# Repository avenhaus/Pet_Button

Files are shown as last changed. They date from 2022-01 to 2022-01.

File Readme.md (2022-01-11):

# ESP32 Talking Pet Button Matrix

<br />
<div align="center">
  <a href="https://github.com/avenhaus/Pet_Button">
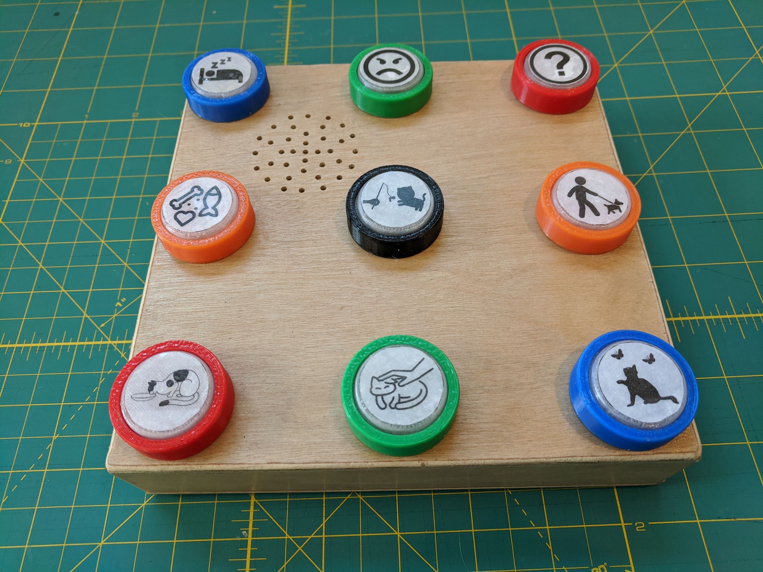
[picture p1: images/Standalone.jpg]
Main Image
    
  </a>
</div>

## Overview

Buttons are arranged on 3 x 3 panels = 9 buttons, requiring 6 wires per panel.
The ESP32 provides 9 inputs by 6 outputs for a support of 6 panels (**54 buttons**) per ESP32.
The audio is stored in ESP32 internal FLASH and played via an I2S amplifier like [MAX98357A](https://www.aliexpress.com/premium/MAX98357A.html?SearchText=MAX98357A)

Current custom 3D printed button is designed for cats or small dogs. It uses a cheap, low profile PCB push button inside and optional SMD LED.

## Advantages

Advantages over commercially available singe recording buttons.

* Better quality and louder audio playback through large 3 watt speaker.
* Higher quality, normalized, de-noised and trimmed recordings using PC microphone and software like [Audacity](https://www.audacityteam.org/)
* Buttons illuminate for additional feedback.
* Much cheaper for large number of buttons.
* Your own choice of button size, feel, look, etc.
* Single, larger battery for all buttons
* Optional AC or USB power

## Build Instructions

### Buttons

* Print icon labels on regular paper.
* Cover with clear packing tape for protection.
* Cut to size with scissors.
* Use CA glue (Super Glue) to attach icons to button caps.
* Hot glue works great to make cheap, leveled non-slip rubber feet. Offset panel on a silicone mat while hot glue cools. (Hot glue removes easily with rubbing alcohol from most surfaces.)

### Audio

* Record audio as 44.1 kHz mono.
* Convert to .m4a (96 kbps) or .mp3 format. .wav works but takes more space.
* Save audio files to to data folder.
* Flash data folder to ESP32 SPIFFS.
* Map audio file to button in *files.h*

## Libraries

* [ESP32-audioI2S](https://github.com/schreibfaul1/ESP32-audioI2S)

## Notes

If there is a noticeable delay between pressing the button and the audio playing, this is due to the default Arduino boot loader being slow to wake up from deep sleep. This can be fixed by flashing a correctly configured IDF boot loader: *bootloader.bin* .

```
.platformio\packages\tool-esptoolpy\esptool.py --chip esp32 --port "COM5" --baud 460800 --before default_reset --after hard_reset write_flash -z --flash_mode dio --flash_freq 40m --flash_size detect 0x1000 bootloader.bin
```

A few of the ESP32 pins can not be switched to output. This means not all buttons can be illuminated.

## Todo

* Code cleanup, license and documentation
* Easier audio management through ESP32 website
* OTA update
* PCB
* 3D printed case

## Images

### Stand alone panel for multiple locations or mobility.
Stand Alone Panel

### Multi panel setup with central audio box for maximum buttons
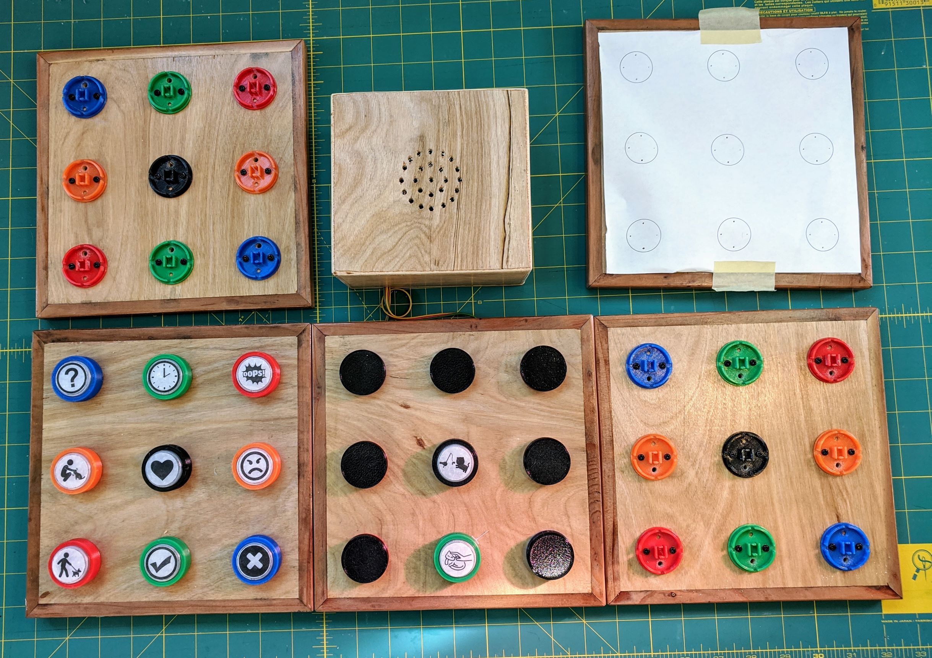
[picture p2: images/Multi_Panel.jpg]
Multi Panel


### Illuminated button
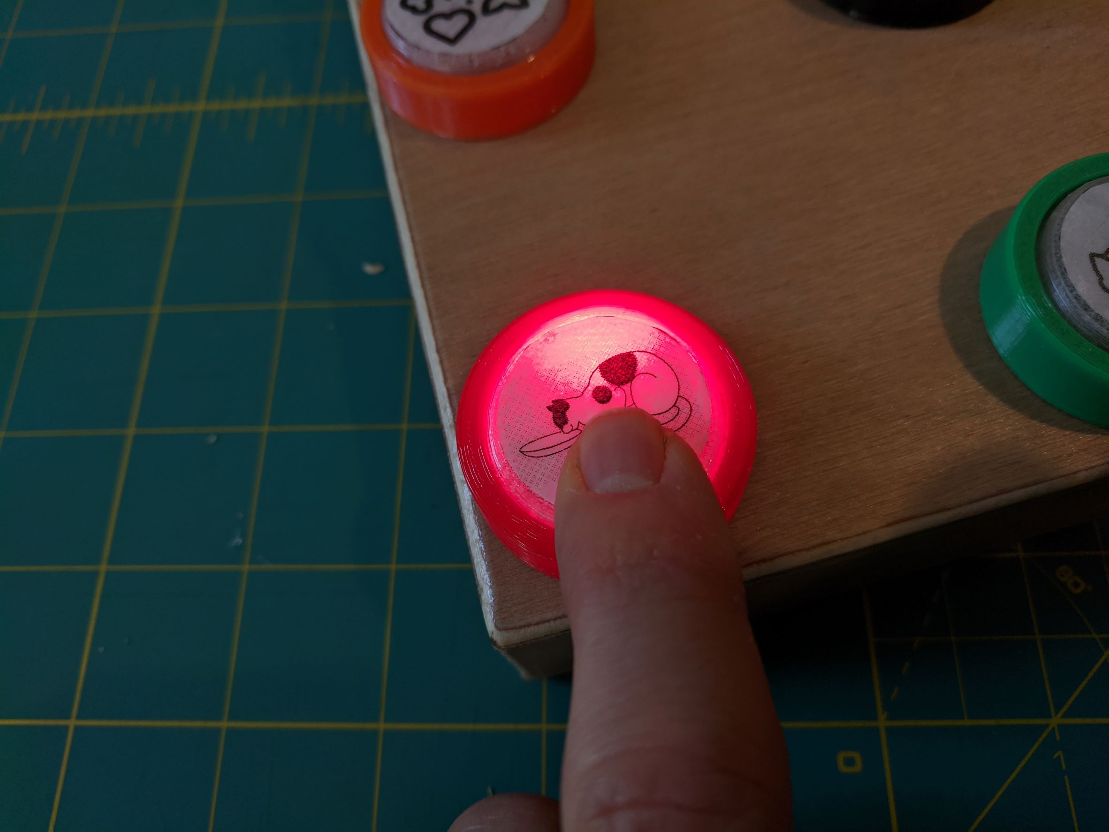
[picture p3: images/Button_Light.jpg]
Button Light


### Button uses cheap PCB push botton and SMD LED
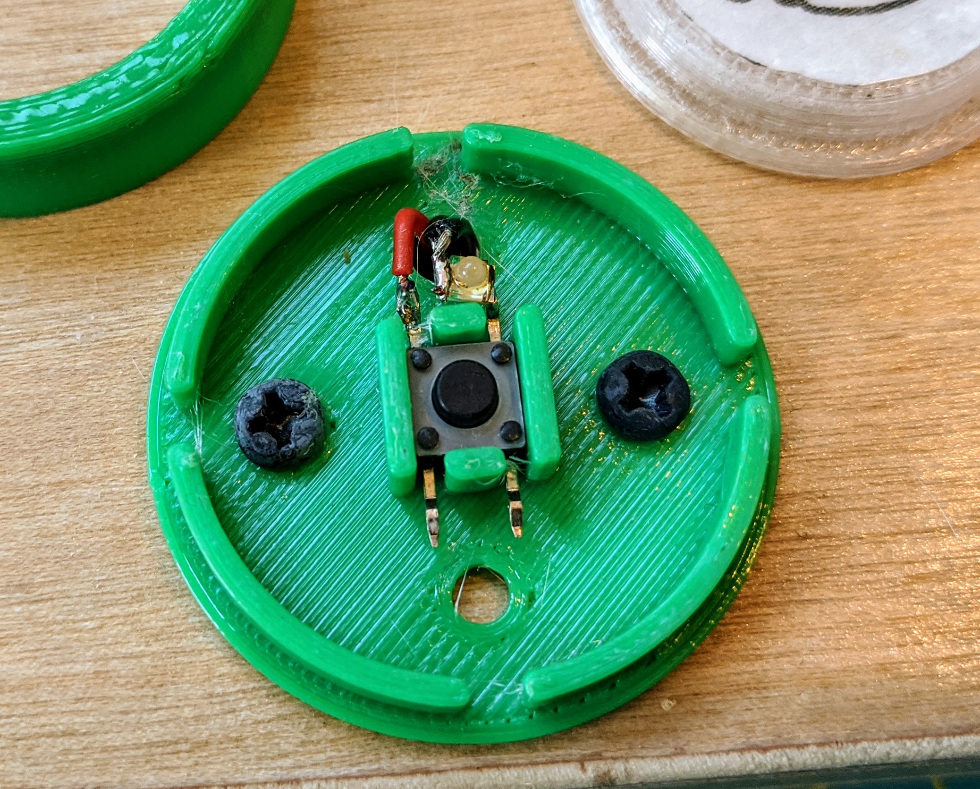
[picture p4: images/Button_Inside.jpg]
Button Inside


### Inside of Stand Alone Panel
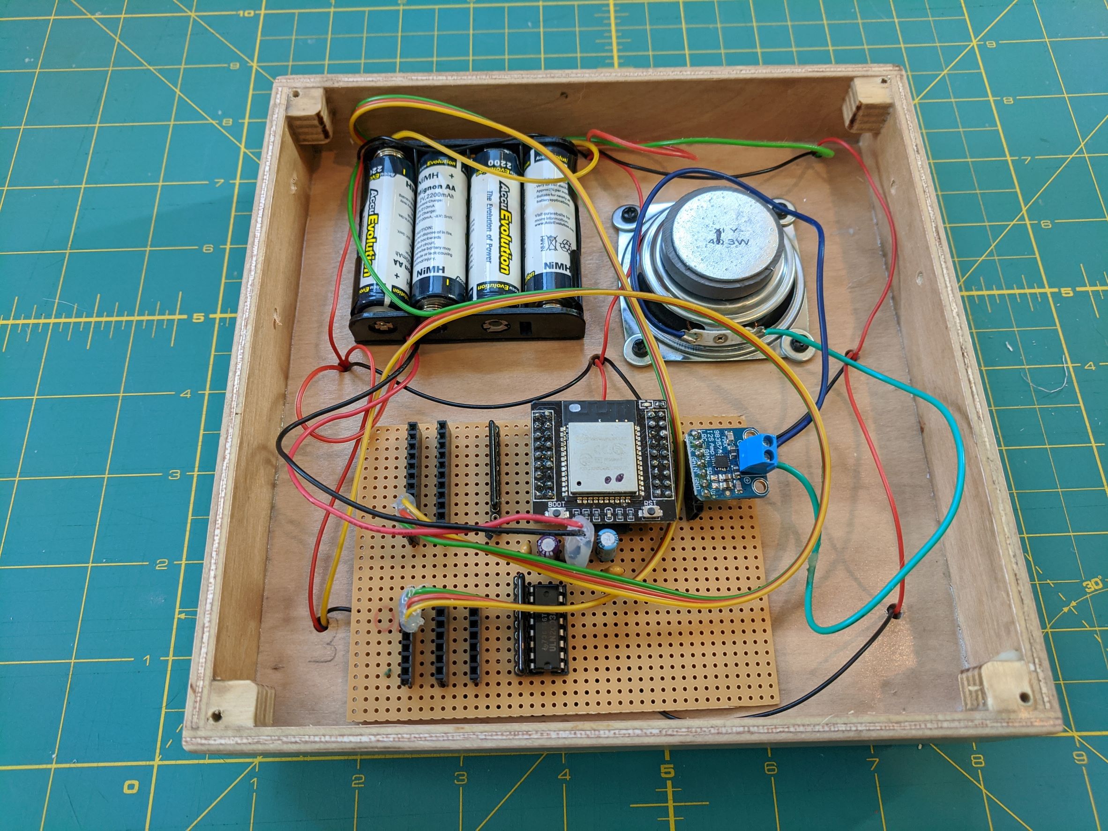
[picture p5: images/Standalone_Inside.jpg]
Standalone Inside


### Top of circuit board
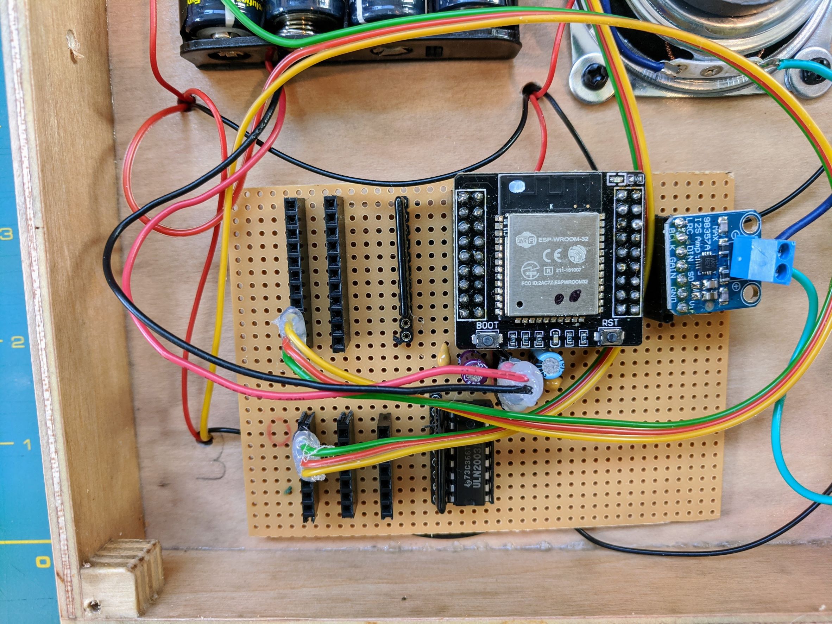
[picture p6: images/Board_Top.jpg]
Board_Top


### Bottom of circuit board
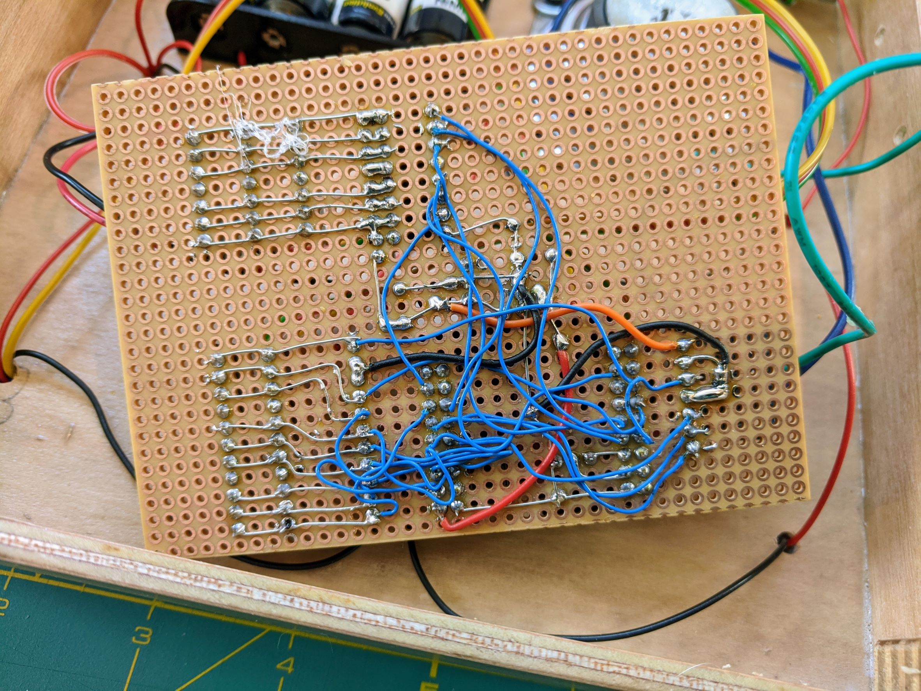
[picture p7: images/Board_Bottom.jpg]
Board_Bottom


### Button panel wiring
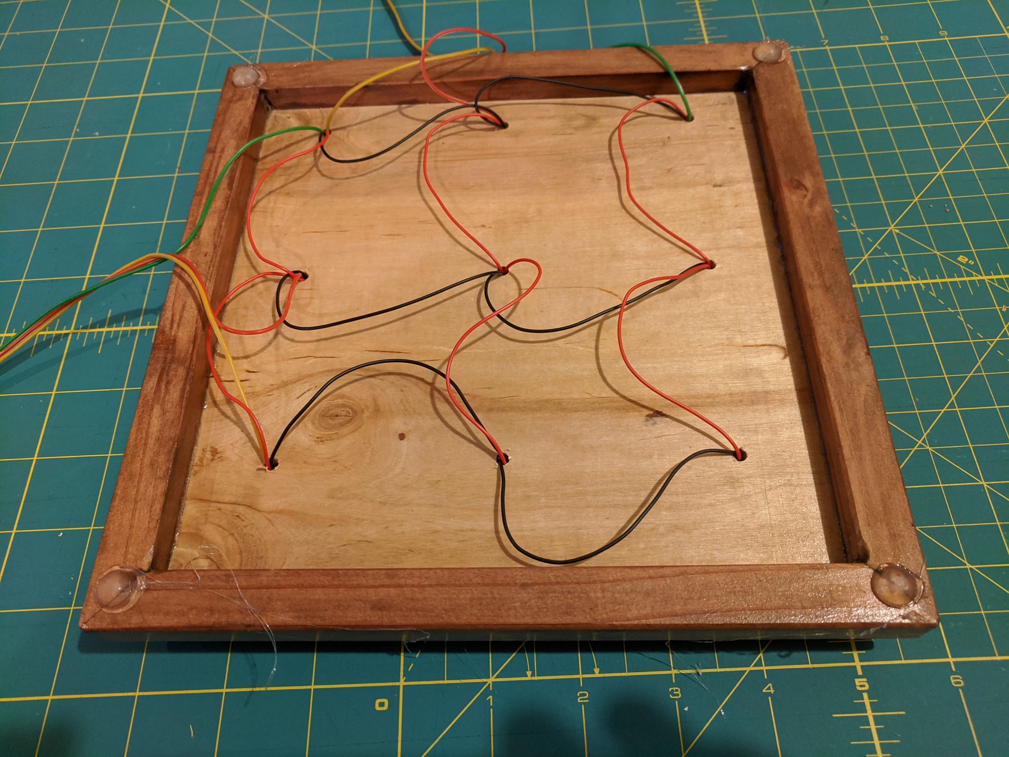
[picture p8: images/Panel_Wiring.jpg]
Panel Wiring


### Hot glue makes great feet
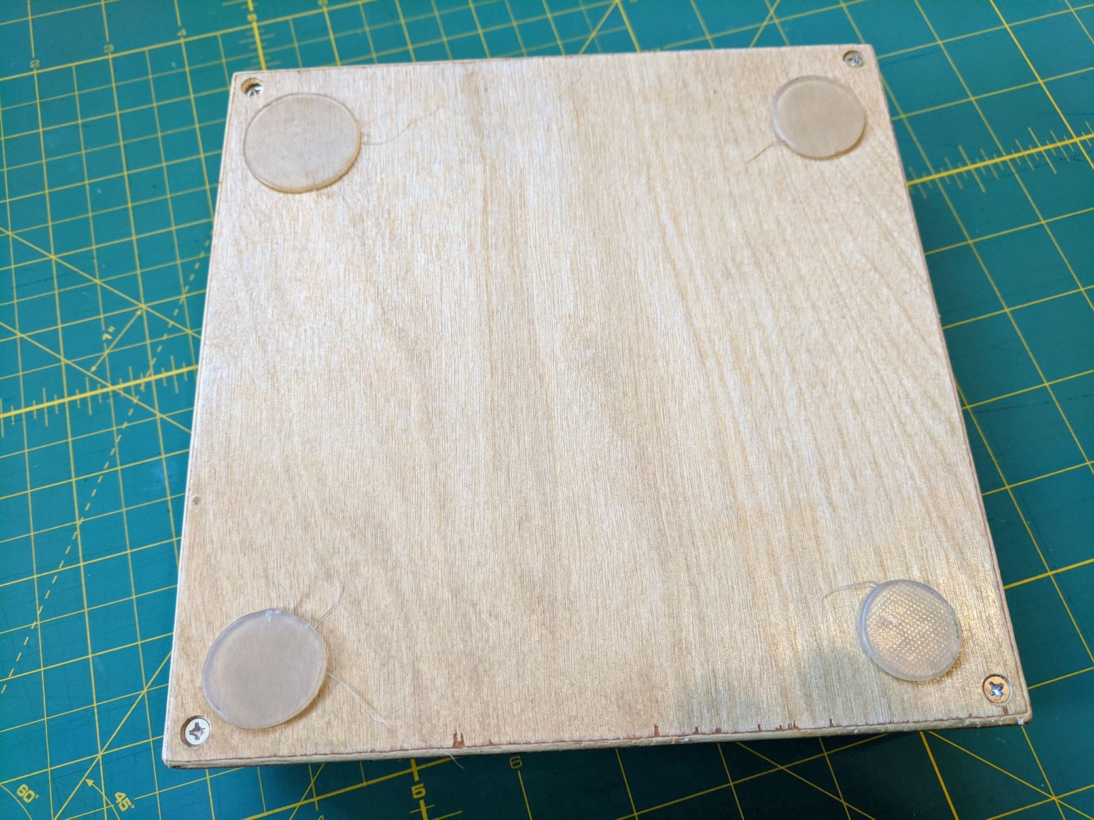
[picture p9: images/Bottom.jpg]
Bottom


### 3D Button Rendering
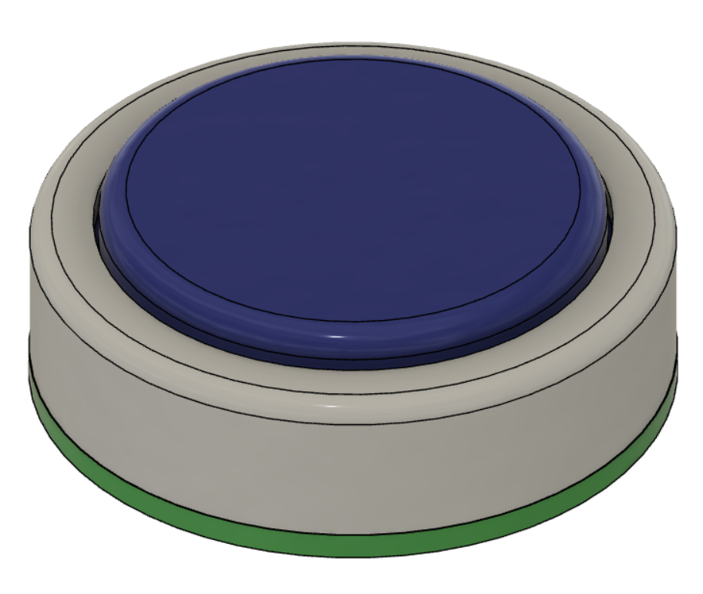
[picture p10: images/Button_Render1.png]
Button Render


### Button cross section
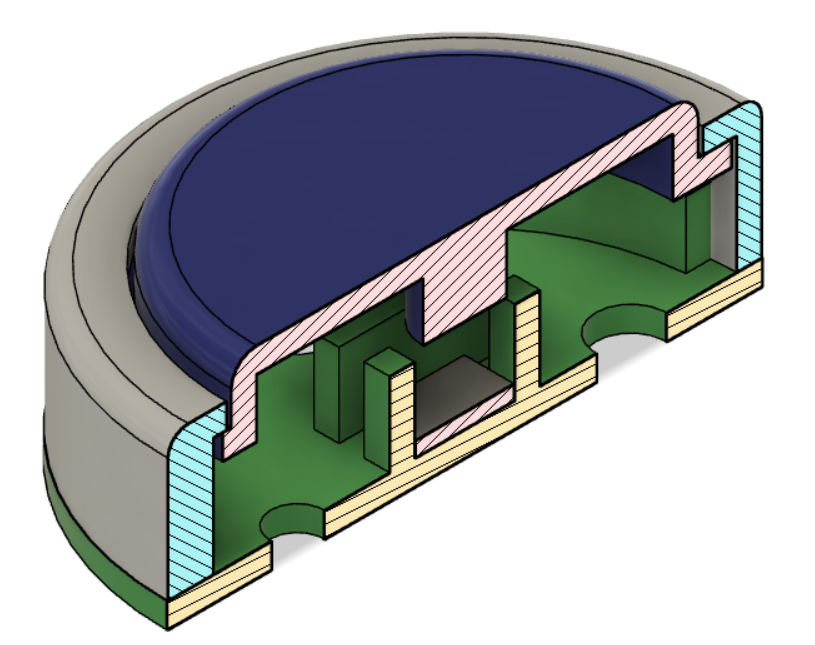
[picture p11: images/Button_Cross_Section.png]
Button Cross Section


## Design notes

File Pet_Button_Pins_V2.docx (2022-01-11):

ESP32 (https://www.espressif.com/sites/default/files/documentation/esp32_technical_reference_manual_en.pdf)
Pinout Reference (https://randomnerdtutorials.com/esp32-pinout-reference-gpios/)

Pin Function Spreadsheet (https://github.com/SensorsIot/ESP32-Deep-Sleep/raw/master/ESP32.xlsx)

22 x I/O + 4 x input only = 26 usable pins

GPIO_34 - GPIO_39 have no internal pullup / pulldown.

The ESP32 chip has the following strapping pins:

- GPIO 0
- GPIO 2
- GPIO 4
- GPIO 5 (must be HIGH during boot)
- GPIO 12 (must be LOW during boot)
- GPIO 15 (must be HIGH during boot)

(Not including GPIO6 to GPIO11 which are used by the internal FLASH and are not useable)

No. | Name | Type | GPIO | Mode | Function | | Note
25 | IO00 | I/O | GPIO00 | | | RTC | Boot mode
35 | TXD0 | I/O | GPIO01 | UART-0 | USB_TXD | | program / debug
24 | IO02 | I/O | GPIO02 | | Key-In-0 | RTC | 10K Pulldown
34 | RXD0 | I/O | GPIO03 | UART-0 | USB _RXD | | program / debug
26 | IO04 | I/O | GPIO04 | | Key-In-1 | RTC | 10K Pulldown
29 | IO05 | I/O | GPIO05 | | SD_CS
20 | SCK/CLK* | I/O | GPIO06 | | Flash | | Do not use!
21 | SDO/SD0* | I/O | GPIO07 | | Flash | | Do not use!
22 | SDI/SD1* | I/O | GPIO08 | | Flash | | Do not use!
17 | SHD/SD2* | I/O | GPIO09 | | Flash | | Do not use!
18 | SWP/SD3* | I/O | GPIO10 | | Flash | | Do not use!
19 | SCS/CMD* | I/O | GPIO11 | | Flash | | Do not use!
14 | IO12 | I/O | GPIO12 | | Key-In-2 | RTC | 10K Pulldown
16 | IO13 | I/O | GPIO13 | | Key-In-3 | RTC | 10K Pulldown
13 | IO14 | I/O | GPIO14 | | Key-In-4 | RTC | 10K Pulldown
23 | IO15 | I/O | GPIO15 | | Key-In-5 | RTC | 10K Pulldown
27 | IO16 | I/O | GPIO16 | | SER
28 | IO17 | I/O | GPIO17 | | SRCLK
30 | IO18 | I/O | GPIO18 | SPI-0 | RCLK
31 | IO19 | I/O | GPIO19 | SPI-0 | POWER_EN | | 100K Pulldown
33 | IO21 | I/O | GPIO21 | I2C-0 | SPI_MOSI
36 | IO22 | I/O | GPIO22 | I2C-0 | SPI_MISO
37 | IO23 | I/O | GPIO23 | SPI-0 | SPI_SCK
10 | IO25 | I/O | GPIO25 | | I2S-DATA | RTC
11 | IO26 | I/O | GPIO26 | | I2S-WS | RTC | LRC
12 | IO27 | I/O | GPIO27 | | I2S-BCK | RTC
8 | IO32 | I/O | GPIO32 | | Key-In-3 | RTC | 10K Pulldown
9 | IO33 | I/O | GPIO33 | | Key-In-4 | RTC | 10K Pulldown
6 | IO34 | I | GPIO34 | | | RTC
7 | IO35 | I | GPIO35 | | | RTC
4 | SENSOR_VP | I | GPIO36 | | | RTC
5 | SENSOR_VN | I | GPIO39 | | | RTC
1 | GND | P
2 | 3V3 | P
3 | EN | I
15 | GND | P
32 | NC
38 | GND | P
39 | GND | P

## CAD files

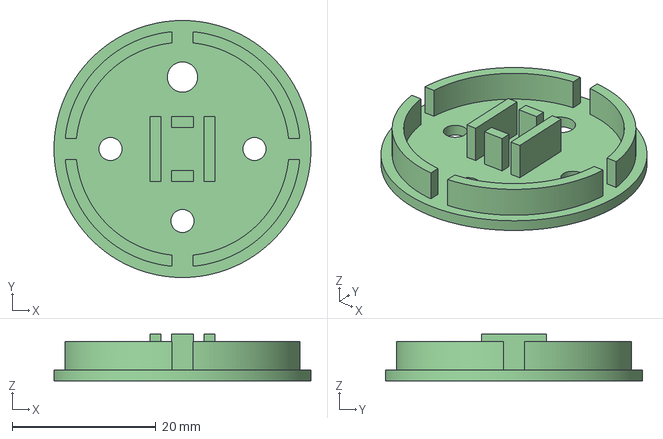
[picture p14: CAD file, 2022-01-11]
CAD/Base.3mf
35.7 x 35.7 x 6.50 mm

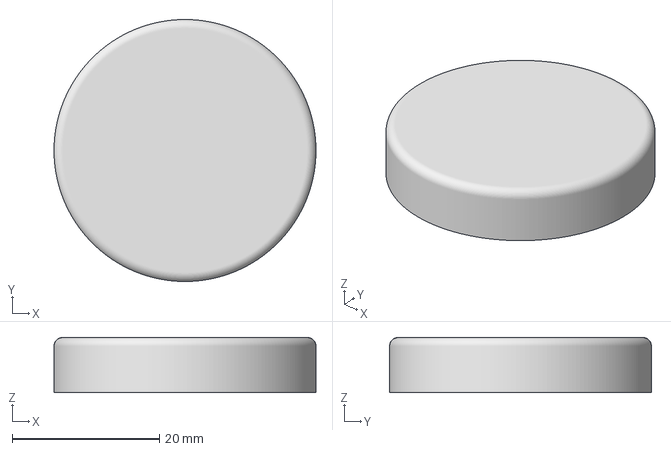
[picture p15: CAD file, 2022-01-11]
CAD/Dummy Cover.3mf
35.6 x 35.6 x 7.50 mm

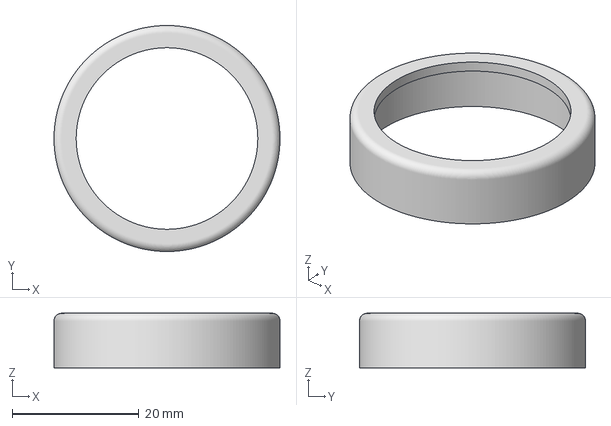
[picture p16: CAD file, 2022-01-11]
CAD/Cover.3mf
35.6 x 35.6 x 8.60 mm

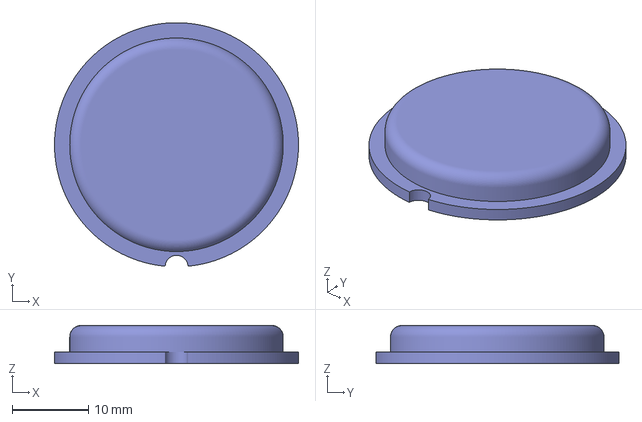
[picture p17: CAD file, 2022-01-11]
CAD/Button.3mf
32.0 x 31.9 x 5.00 mm

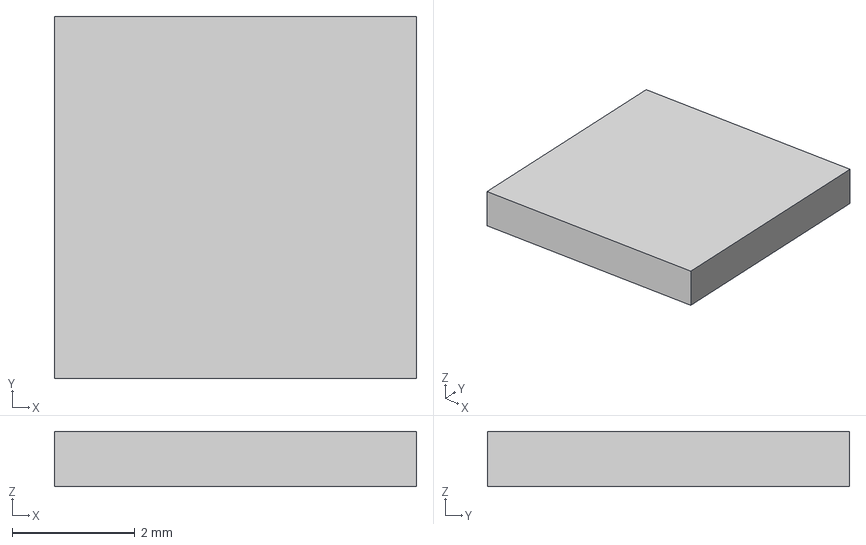
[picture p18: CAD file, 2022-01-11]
CAD/Spacer.3mf
5.90 x 5.90 x 0.9 mm

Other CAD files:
CAD/Pet_Button.f3d

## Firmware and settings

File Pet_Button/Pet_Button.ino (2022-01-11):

//**********************************************************************************************************
//*   Pet Word Player                                                             *
//**********************************************************************************************************
//
// Arduino bootloader is slow to wake up and can not be customized. Flash PlatformIO bootloader:
//  pio run -t menuconfig
// The menuconfig target is only available for ESP-IDF framework and Arduino uses prebuilt ESP-IDF so it's not configurable.
// pio run -v -t upload
// C:\Users\caavenha\.platformio\packages\tool-esptoolpy\esptool.py --chip esp32 --port "COM5" --baud 460800 --before default_reset --after hard_reset write_flash -z --flash_mode dio --flash_freq 40m --flash_size detect 0x1000 C:\Repos\ESP32\Pet-Button\.pio\build\esp32dev\bootloader.bin

#include "Arduino.h"
#include "WiFiMulti.h"
#include "driver/adc.h"
#include <esp_bt.h>
#include "Audio.h"
#include "SPI.h"
#include "SD.h"
#include "FS.h"
#include "SPIFFS.h"
#include "driver/rtc_io.h"


// Idle Power: 
// 85uA with ULN2003 and MAX98357 disabled
// 350uA with 100K output pullups to  +5V - ESP32 clamping to 3.3V
// 400uA with MAX98357 enabled (1M pullup not removed) and no pullups
// 675uA with 100K pullups and MAX98357 enabled



/********************************************\
|*  Pin Definitions
\********************************************/

// Buttons are arranged on 3 x 3 panels = 9 buttons, requiring 6 wires
// Button matrix is 9 inputs by 6 outputs for a support of 54 Buttons

// Button Inputs - 100K pulldown to allow deep sleep
#define BIN_0   2
#define BIN_1   4
#define BIN_2   12
#define BIN_3   32
#define BIN_4   33
#define BIN_5   34
#define BIN_6   35
#define BIN_7   36
#define BIN_8   39

const uint64_t WAKE_MASK = (1LL<<BIN_0) | (1LL<<BIN_1) | (1LL<<BIN_2) |
                           (1LL<<BIN_3) | (1LL<<BIN_4) | (1LL<<BIN_5) |
                           (1LL<<BIN_6) | (1LL<<BIN_7) | (1LL<<BIN_8);
                           
// Button Open Drain Outputs - 220 pullup to 5V to allow wakeup on any button
#define BOUT_0   13
#define BOUT_1   14
#define BOUT_2   15
#define BOUT_3   16
#define BOUT_4   17
#define BOUT_5   18

#define USE_ULN2003   1


// I2S Audio Amplifier
#define I2S_DOUT      25
#define I2S_BCLK      27
#define I2S_LRC       26

// Amplifier Power Enable - Also Boot button, so use open drain...
#define POWER_EN 19

// SD Card (optional)
#define SD_CS          5
#define SPI_MOSI      21
#define SPI_MISO      22
#define SPI_SCK       23


/* ============================================== *\
 * Debug
\* ============================================== */

#define SERIAL_DEBUG 1
#define SERIAL_SPEED 115200

#if SERIAL_DEBUG < 1
#define DEBUG_println(...) 
#define DEBUG_print(...) 
#define DEBUG_printf(...) 
#else
#define DEBUG_println(...) if (debugStream) {debugStream->println(__VA_ARGS__);}
#define DEBUG_print(...) if (debugStream) {debugStream->print(__VA_ARGS__);}
#define DEBUG_printf(...) if (debugStream) {debugStream->printf(__VA_ARGS__);}
#endif

#define FST (const char *)F
#define PM (const __FlashStringHelper *)

/* ============================================== *\
 * Data
\* ============================================== */

const char version_number[] PROGMEM = "0.2";
const char version_date[] PROGMEM = __DATE__;
const char version_time[] PROGMEM = __TIME__;

const uint8_t KEY_IN[9] = { BIN_0, BIN_1, BIN_2, BIN_3, BIN_4, BIN_5, BIN_6, BIN_7, BIN_8 };
const uint8_t KEY_OUT[7] = { BOUT_0, BOUT_1, BOUT_2, BOUT_3, BOUT_4, BOUT_5 };

static uint64_t old_keys = 0;
static uint64_t keys = 0;

static uint8_t queue[32];
static uint8_t q_size = 0;
static uint8_t q_write = 0;
static uint8_t q_read = 0;

static bool is_playing = false;

static uint32_t time_ms = 0;

Stream* debugStream = &Serial;
Audio audio;

WiFiMulti wifiMulti;
const char ssid[] PROGMEM =     "My-Wifi-Network";
const char password[] PROGMEM = "Wifi-Password";

#include "files.h"

void setup() {
  Serial.begin(SERIAL_SPEED);
  DEBUG_print(F("Cat Button\n"));
  //DEBUG_printf(FST("\n\nPet Buttons Version %s | %s | %s\n\n"), version_number, version_date, version_time);

  for (int i=0; i<9; i++) { pinMode(KEY_IN[i], INPUT); }
#if USE_ULN2003
  for (int i=0; i<6; i++) { pinMode(KEY_OUT[i], OUTPUT); digitalWrite(KEY_OUT[i], LOW); }
#else
  for (int i=0; i<6; i++) { pinMode(KEY_OUT[i], OUTPUT_OPEN_DRAIN); digitalWrite(KEY_OUT[i], HIGH); }
#endif
  PIN_FUNC_SELECT(GPIO_PIN_MUX_REG[4], PIN_FUNC_GPIO);
  PIN_FUNC_SELECT(GPIO_PIN_MUX_REG[12], PIN_FUNC_GPIO);

  
  pinMode(POWER_EN, OUTPUT); digitalWrite(POWER_EN, HIGH);

  #if USE_SD
    pinMode(SD_CS, OUTPUT); digitalWrite(SD_CS, HIGH);
    SPI.begin(SPI_SCK, SPI_MISO, SPI_MOSI);
    SPI.setFrequency(1000000);
    SD.begin(SD_CS);
  #endif


  if (esp_sleep_get_wakeup_cause() == ESP_SLEEP_WAKEUP_EXT1) {
    print_wakeup_reason();
  
    int GPIO_reason = esp_sleep_get_ext1_wakeup_status();
    DEBUG_print(F("GPIO that triggered the wake up: GPIO "));
    DEBUG_println((log(GPIO_reason))/log(2), 0);
  
    memset(queue, 0, sizeof(queue));
    keys = get_keys();
    // DEBUG_printf(FST("Keys: %llX\n"), keys);
  

    if(!SPIFFS.begin(true)){
      DEBUG_print(F("SPIFFS Mount Failed"));
    }
    audio.setPinout(I2S_BCLK, I2S_LRC, I2S_DOUT);
    audio.setVolume(21); // 0...21
    if (q_size) { play_next(); }
  }
  else {
    if(!SPIFFS.begin(true)){
      DEBUG_print(F("SPIFFS Mount Failed"));
    }
    list_dir(SPIFFS, "/", 0);
    go_sleep();
  }
  time_ms = millis();
}

void loop()
{
  audio.loop();
  uint32_t ms = millis();
  if ( ms - time_ms >= 10 || ms < time_ms ) {
    keys = get_keys();
    time_ms = ms;
  }
  if (!is_playing && !keys) {
    go_sleep();
  }
}


inline void set_out(uint8_t n) {
  // DEBUG_printf(FST("Out: %X\n"), n);
  for (uint8_t i=0; i<6; i++) {
#if USE_ULN2003
    digitalWrite(KEY_OUT[i], !(n & 1));
#else
    digitalWrite(KEY_OUT[i], n & 1);
#endif
    n = n >> 1;
  }
}

inline uint16_t get_in() {
  uint16_t n = 0;
  for (int i=8; i>=0; i--) {
    n = n << 1;
    n |= digitalRead(KEY_IN[i]);
    // DEBUG_printf(FST("(%d %d 0x%X) "), i, KEY_IN[i], n);
  }
  // DEBUG_printf(FST("In: %X\n"), n);
  return n;
}

uint64_t get_keys() {
  for (int i=0; i<9; i++) { pinMode(KEY_IN[i], INPUT); }
  uint64_t keys = 0;
  uint8_t out = 1;
  for (int i=0; i<6; i++) {
    set_out(out);
    out = out << 1;
    keys |= ((uint64_t) get_in()) << (i*9);
  }
  set_out(0xFF); // Go high to not waste power on the pullups
  uint64_t n = (old_keys ^ keys) & keys;
  for (int i=0; i<64; i++) {
    if (n & 1) {
      push(i);    
    }
    n = n >> 1;
  }
  old_keys = keys;
  for (int i=0; i<9; i++) { pinMode(KEY_IN[i], OUTPUT); }
  return keys;
}


void list_dir(fs::FS &fs, const char * dirname, uint8_t levels){
   DEBUG_printf(FST("Listing directory: %s\r\n"), dirname);

   File root = fs.open(dirname);
   if(!root){
      DEBUG_println(F("− failed to open directory"));
      return;
   }
   if(!root.isDirectory()){
      DEBUG_println(F(" − not a directory"));
      return;
   }

   File file = root.openNextFile();
   while(file){
      if(file.isDirectory()){
         DEBUG_print(F("  DIR : "));
         DEBUG_println(file.name());
         if(levels){
            list_dir(fs, file.name(), levels -1);
         }
      } else {
         DEBUG_print(F("  FILE: "));
         DEBUG_print(file.name());
         DEBUG_print(F("\tSIZE: "));
         DEBUG_println(file.size());
      }
      file = root.openNextFile();
   }
}


void print_wakeup_reason(){
  esp_sleep_wakeup_cause_t wakeup_reason;

  wakeup_reason = esp_sleep_get_wakeup_cause();

  switch(wakeup_reason)
  {
    case ESP_SLEEP_WAKEUP_EXT0 : DEBUG_print(F("Wakeup caused by external signal using RTC_IO")); break;
    case ESP_SLEEP_WAKEUP_EXT1 : DEBUG_print(F("Wakeup caused by external signal using RTC_CNTL")); break;
    case ESP_SLEEP_WAKEUP_TIMER : DEBUG_print(F("Wakeup caused by timer")); break;
    case ESP_SLEEP_WAKEUP_TOUCHPAD : DEBUG_print(F("Wakeup caused by touchpad")); break;
    case ESP_SLEEP_WAKEUP_ULP : DEBUG_print(F("Wakeup caused by ULP program")); break;
    default : DEBUG_printf(FST("Wakeup was not caused by deep sleep: %d\n"), wakeup_reason); break;
  }
}

void go_sleep() {
    DEBUG_println(F("Sleep now"));

    digitalWrite(POWER_EN, LOW);
    
    // RTC IO pins: 0,2,4,12-15,25-27,32-39.
    esp_sleep_enable_ext1_wakeup(WAKE_MASK, ESP_EXT1_WAKEUP_ANY_HIGH);
    
    adc_power_off();
    WiFi.disconnect(true);  // Disconnect from the network
    WiFi.mode(WIFI_OFF);    // Switch WiFi off
    btStop();
    

    // Isolate GPIO12 pin from external circuits. This is needed for modules
    // which have an external pull-up resistor on GPIO12 (such as ESP32-WROVER)
    // to minimize current consumption.
    // rtc_gpio_isolate(GPIO_NUM_4);
    // rtc_gpio_isolate(GPIO_NUM_12);
    // delay(100);


    esp_deep_sleep_start(); 
}


void play_next () {
  is_playing = false;
  if (q_size) {
    int8_t b = pop();
    const char* f = files[b];
    if (f) {
      char buffer[64];
      sprintf(buffer, FST("/%s.m4a"), f);   
      DEBUG_printf(FST("Play file: '%s'\n"), buffer);
      audio.connecttoFS(SPIFFS, buffer);
      is_playing = true;
    } else {
      //play_unknown_button(b);
    }
  }
}

void play_unknown_button(uint8_t n) {
    WiFi.mode(WIFI_STA);
    wifiMulti.addAP(ssid, password);
    wifiMulti.run();
    if(WiFi.status() != WL_CONNECTED){
      DEBUG_printf(FST("Could not connect to WIFI. Error: %d\n"), WiFi.status());
      WiFi.disconnect(true);
      wifiMulti.run();
      play_next();
      return;
    }
    char buffer[32];
    sprintf(buffer, FST("Button %d"), n);    
    DEBUG_printf(FST("Play TTS: '%s'\n"), buffer);
    audio.connecttospeech(buffer, FST("us"));
    is_playing = true;
}
    

/********************************************\
|* Queue
\********************************************/

inline void push(uint8_t i) {
  if (q_size >= sizeof(queue)) { return; }
  DEBUG_printf(FST("Push: %u\n"), i);
  queue[q_write++] = i;
  if (q_write >= sizeof(queue)) { q_write = 0; }
  q_size++;
}

inline int8_t pop(void) {
  int8_t i = -1;
  if (q_size  == 0) { return -1; }
  i = queue[q_read++];
  if (q_read >= sizeof(queue)) { q_read = 0; }
  q_size--;
  DEBUG_printf(FST("Pop: %u\n"), i);
  return i;
}

/********************************************\
|*  Event Handlers
\********************************************/

void audio_info(const char *info){
    DEBUG_print(F("info        ")); DEBUG_println(info);
}
void audio_id3data(const char *info){  //id3 metadata
    DEBUG_print(F("id3data     ")); DEBUG_println(info);
}
void audio_eof_mp3(const char *info){  //end of file
    DEBUG_print(F("eof_mp3     ")); DEBUG_println(info);
    play_next();
}
void audio_showstation(const char *info){
    DEBUG_print(F("station     ")); DEBUG_println(info);
}
void audio_showstreamtitle(const char *info){
    DEBUG_print(F("streamtitle ")); DEBUG_println(info);
}
void audio_bitrate(const char *info){
    DEBUG_print(F("bitrate     ")); DEBUG_println(info);
}
void audio_commercial(const char *info){  //duration in sec
    DEBUG_print(F("commercial  ")); DEBUG_println(info);
}
void audio_icyurl(const char *info){  //homepage
    DEBUG_print(F("icyurl      ")); DEBUG_println(info);
}
void audio_lasthost(const char *info){  //stream URL played
    DEBUG_print(F("lasthost    ")); DEBUG_println(info);
}
void audio_eof_speech(const char *info){
    DEBUG_print(F("eof_speech  ")); DEBUG_println(info);
    play_next();
}
